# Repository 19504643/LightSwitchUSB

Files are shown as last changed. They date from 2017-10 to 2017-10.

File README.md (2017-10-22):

# SushiBits LightSwitch-USB

This is a simple-ish USB-controlled LED light switch, intended to be used along
with IKEA USB powered LED lights.

For me this gadget is intended to play nice with my KVM tree, which would share
the LED Lamp (along with other peripherals) across computers. This is one of the
reason why a custom USB device is needed, since being a full USB device would
allow the computer, and the software running on it, to tell if the LED is online
or not. It also tells whether the computer is active on KVM or not.

## Comapnion Software:

* Firmware: https://github.com/SushiBits/LightSwitchUSB-Firmware
* Host software for macOS: https://github.com/SushiBits/LightSwitchUSB-Mac
* Host software for Windows
* Host software for Linux

## License and Contact

This project is licensed under the [3-clause BSD license](LICENSE.md).

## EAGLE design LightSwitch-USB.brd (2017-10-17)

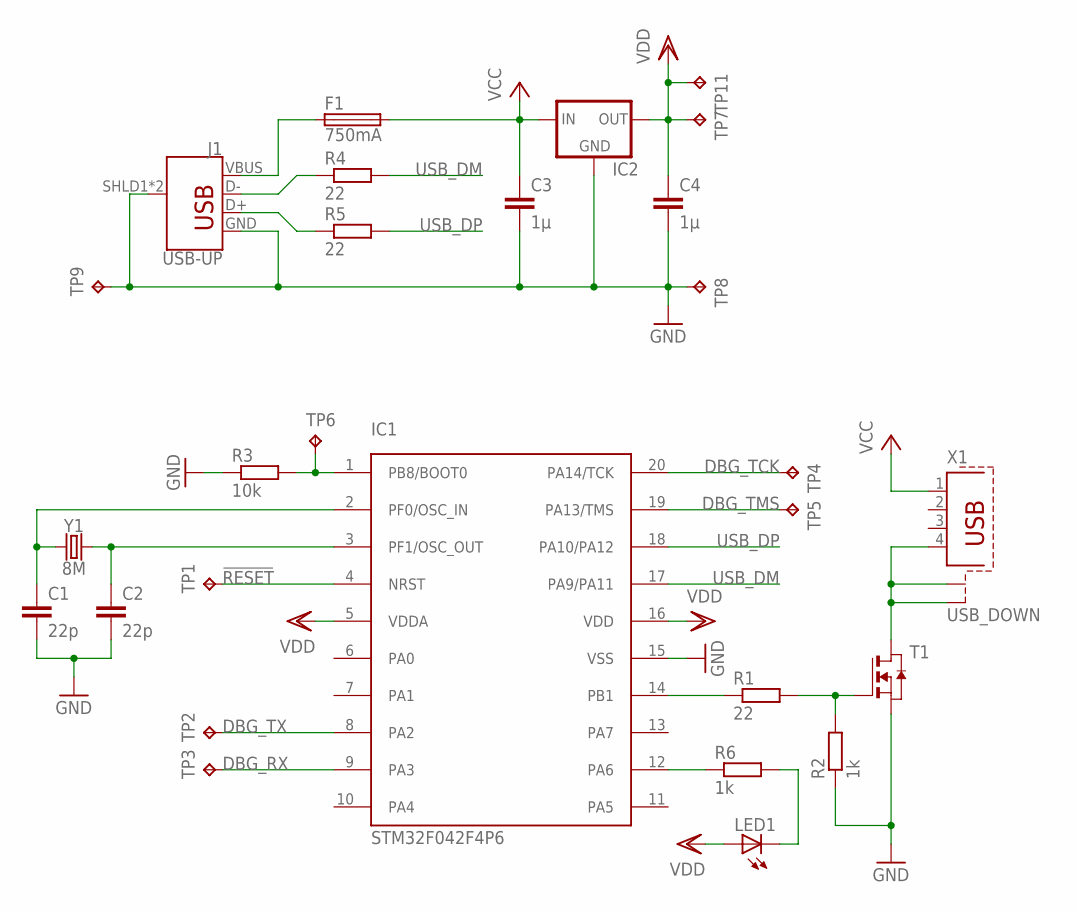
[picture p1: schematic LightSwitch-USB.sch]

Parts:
C1, C2: 22p; C0603
C3, C4: 1µ; C0603
F1: 750mA; R1206
IC1: STM32F042F4P6; TSSOP20
IC2: XC63FPM; SOT23
J1: USB-UP; USB-A-H
LED1: LEDCHIP-LED0805; CHIP-LED0805
R1, R4, R5: 22; R0603
R2, R6: 1k; R0603
R3: 10k; R0603
T1: NMOSSOT23; SOT-23
TP1, TP2, TP3, TP4, TP5, TP6, TP7, TP8, TP9, TP11: TPB1,27; B1,27
X1: USB_DOWN; PN87520-S
Y1: 8M; CRYSTAL-SMD-5X3.2-2PAD

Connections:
!RESET: IC1.4 (NRST), TP1.TP
DBG_RX: IC1.9 (PA3), TP3.TP
DBG_TCK: IC1.20 (PA14/TCK), TP4.TP
DBG_TMS: IC1.19 (PA13/TMS), TP5.TP
DBG_TX: IC1.8 (PA2), TP2.TP
GND: C1.2, C2.2, C3.2, C4.2, IC1.15 (VSS), IC2.1 (GND), J1.GND, J1.SHLD1 (SHIELD), J1.SHLD2 (SHIELD), R2.1, R3.1, T1.2 (S), TP8.TP, TP9.TP
unnamed: T1.1 (D), X1.4, X1.S1, X1.S2
unnamed: LED1.C, R6.2
unnamed: IC1.12 (PA6), R6.1
OUT_DRV: IC1.14 (PB1), R1.1
OUT_GATE: R1.2, R2.2, T1.3 (G)
SYS_BOOT: IC1.1 (PB8/BOOT0), R3.2, TP6.TP
SYS_XIN: C1.1, IC1.2 (PF0/OSC_IN), Y1.P$1 (1)
SYS_XOUT: C2.1, IC1.3 (PF1/OSC_OUT), Y1.P$2 (2)
USB+: J1.D+, R5.1
USB-: J1.D-, R4.1
USB_DM: IC1.17 (PA9/PA11), R4.2
USB_DP: IC1.18 (PA10/PA12), R5.2
VBUS: F1.1, J1.VBUS
VCC: C3.1, F1.2, IC2.3 (IN), X1.1
VDD: C4.1, IC1.5 (VDDA), IC1.16 (VDD), IC2.2 (OUT), LED1.A, TP7.TP, TP11.TP

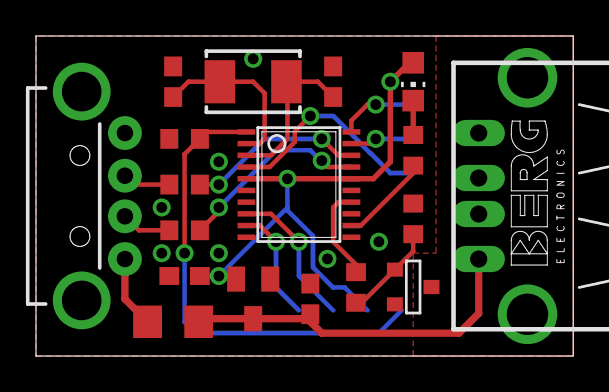
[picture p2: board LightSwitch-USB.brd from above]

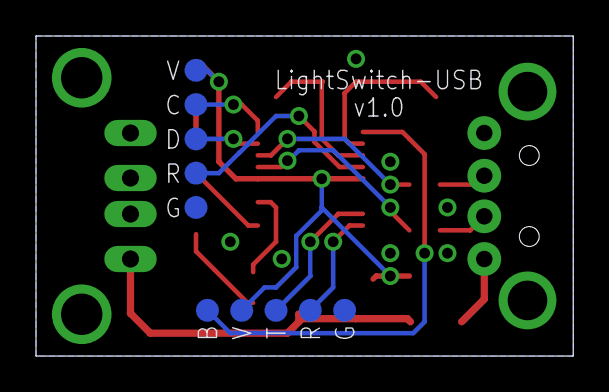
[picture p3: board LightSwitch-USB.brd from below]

Board: 2 copper layers, 29.8 x 17.8 mm, 28 parts (10 on the bottom side), 21 nets.

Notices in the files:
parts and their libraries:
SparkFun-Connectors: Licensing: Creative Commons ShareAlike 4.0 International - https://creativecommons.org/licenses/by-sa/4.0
